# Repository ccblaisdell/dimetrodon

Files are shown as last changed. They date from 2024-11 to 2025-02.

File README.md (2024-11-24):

# Dimetrodon
A 36 key split keyboard with stagger and splay, built with Ergogen.

## Images
| Top | Bottom |
| --- | --- |
| top | bottom |

## Development

- Clone the git repository.
- Install NodeJS.
- Run `npm install`.
- Run `make build`.

## Case

### Development

When exporting the PCB STEP file from Kicad, be sure to choose the "Board center origin"
choice for the Coordinates option. This will undo the [100, -100] movement we define
in ergogen to make the file easier to work with in Kicad and center the model in 3d space.

## Acknowledgements

- Ergogen
- Rae-dux
- Totem
- FlatFootFox
- linalinn/kicad-render
- Scottokeebs

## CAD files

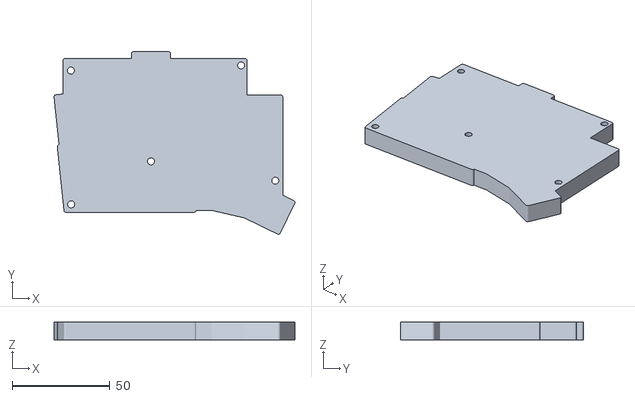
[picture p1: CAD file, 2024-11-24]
cases/case.stl
123.1 x 93.2 x 9.10

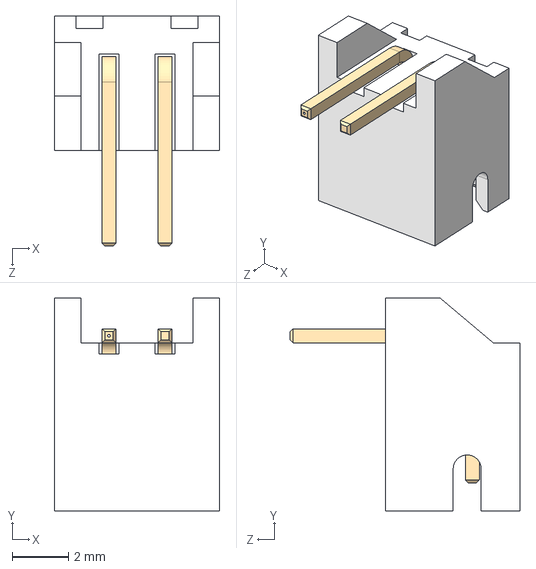
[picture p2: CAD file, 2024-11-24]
ergogen/3dmodels/JST-S2B-PH-K-S.STEP
5.90 x 7.60 x 8.20 mm

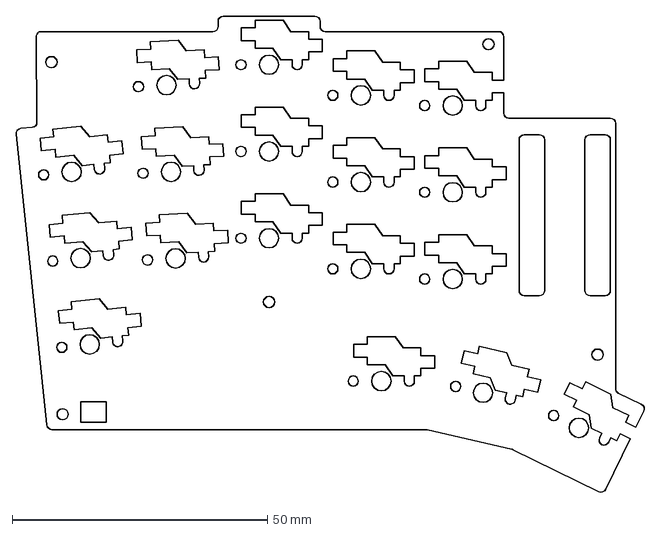
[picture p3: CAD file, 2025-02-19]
outlines/case_base_right.dxf
123.3 x 93.4 mm

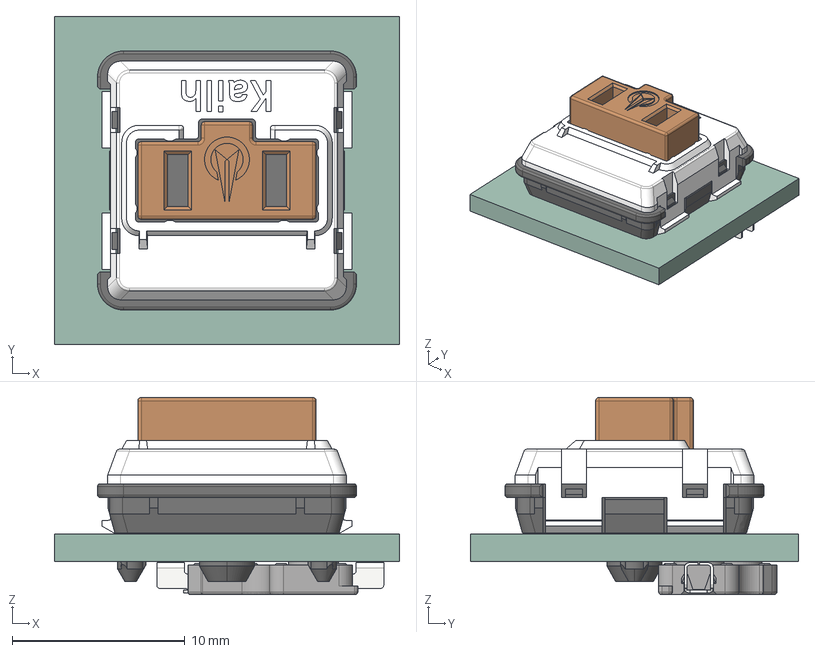
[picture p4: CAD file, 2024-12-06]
pcbs/single-choc-v1-hotswap.step
20.0 x 19.0 x 11.4 mm
SW_Hotswap_Kailh_Choc_v1
SW_Kailh_Choc_V1_cp
main (2)_PCB

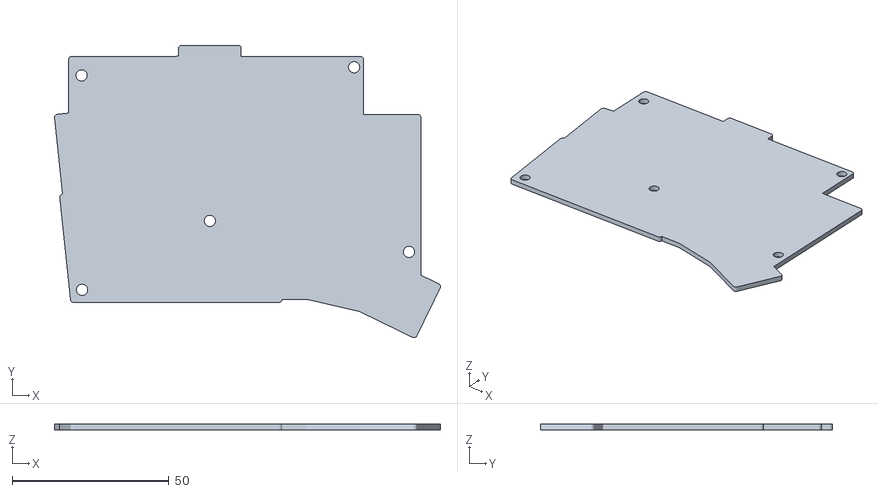
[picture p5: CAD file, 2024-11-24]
cases/cork_base.stl
123.1 x 93.2 x 1.80

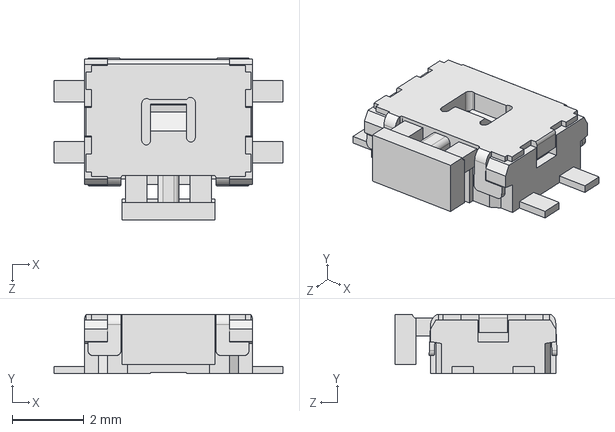
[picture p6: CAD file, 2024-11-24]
ergogen/3dmodels/EVQPU-JA-02K.STEP
6.40 x 1.65 x 4.54 mm

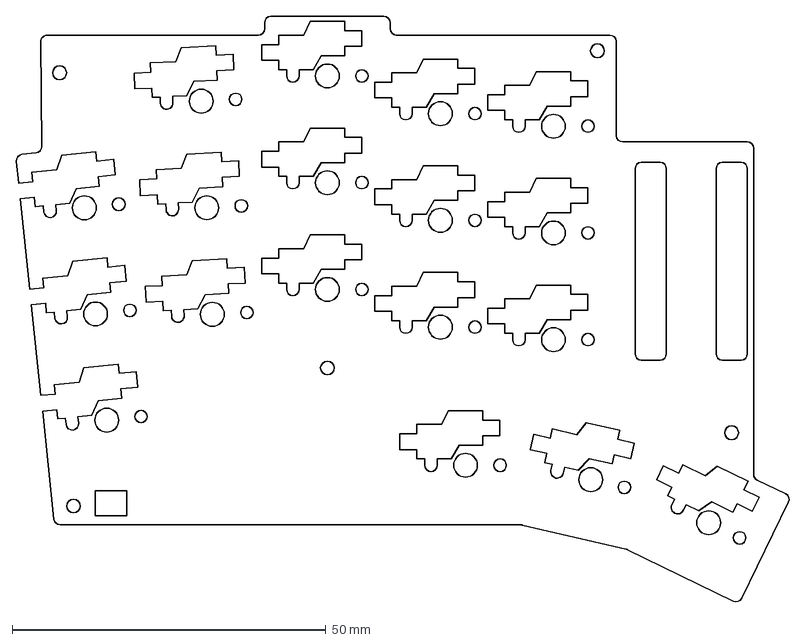
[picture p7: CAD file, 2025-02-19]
outlines/case_base_left.dxf
123.3 x 93.4 mm

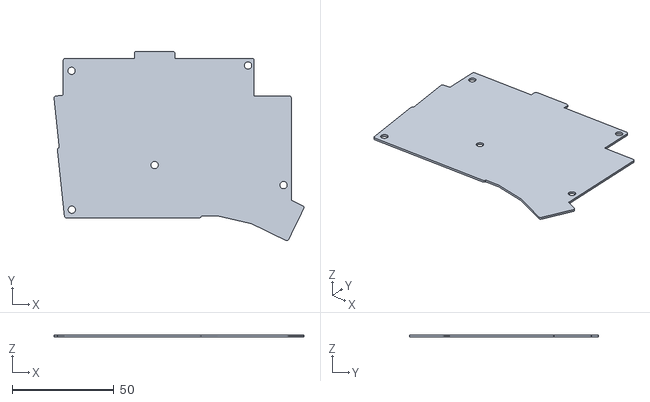
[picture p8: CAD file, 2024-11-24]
cases/silicone_base.stl
123.1 x 93.2 x 1.00

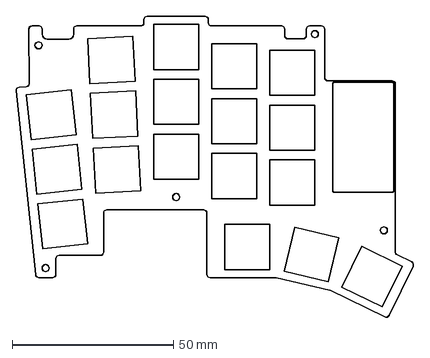
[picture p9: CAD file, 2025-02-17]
outlines/switch_plate.dxf
123.3 x 93.4 mm

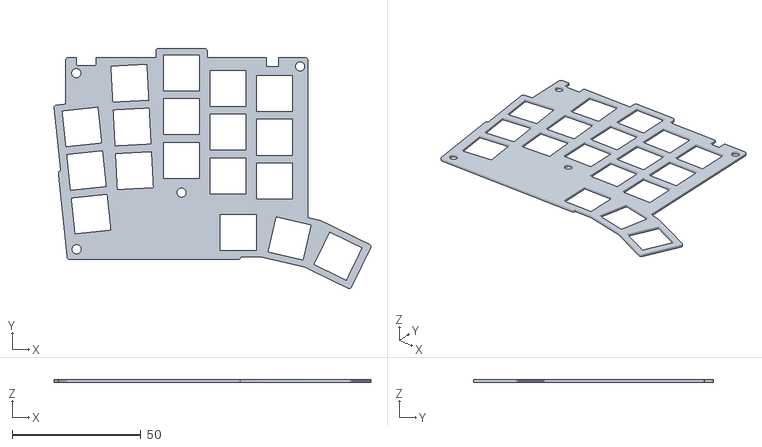
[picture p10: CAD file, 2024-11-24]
cases/gasket.stl
123.1 x 93.2 x 1.00

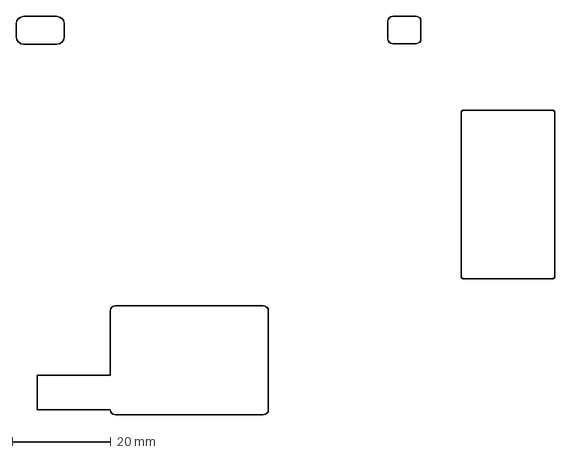
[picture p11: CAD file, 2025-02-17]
outlines/cavities.dxf
108.9 x 80.5 mm

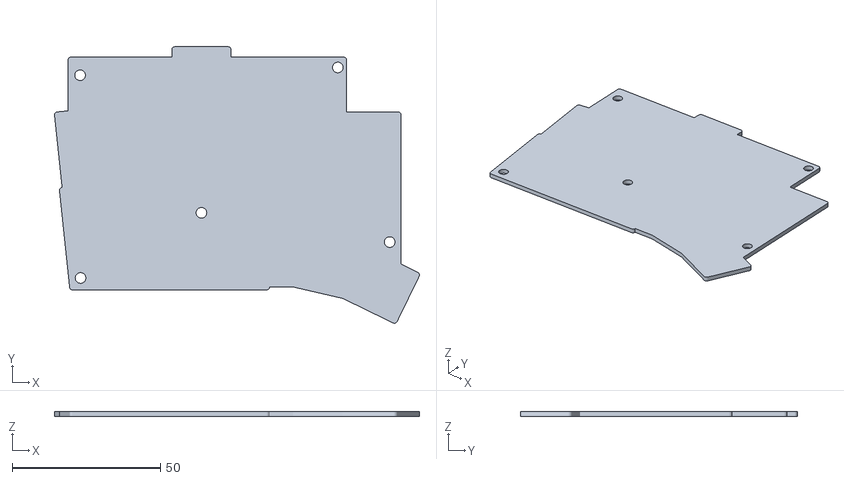
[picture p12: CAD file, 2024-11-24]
cases/pcb.stl
123.1 x 93.2 x 1.60

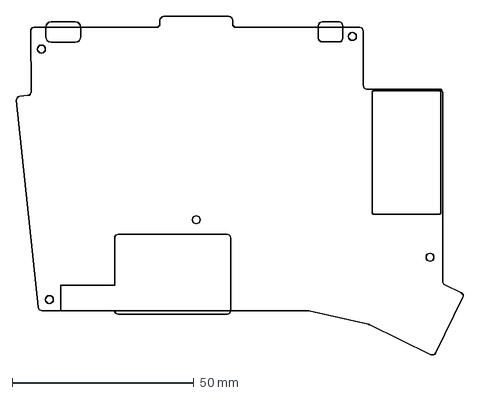
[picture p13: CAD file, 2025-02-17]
outlines/debug.dxf
123.3 x 93.4 mm

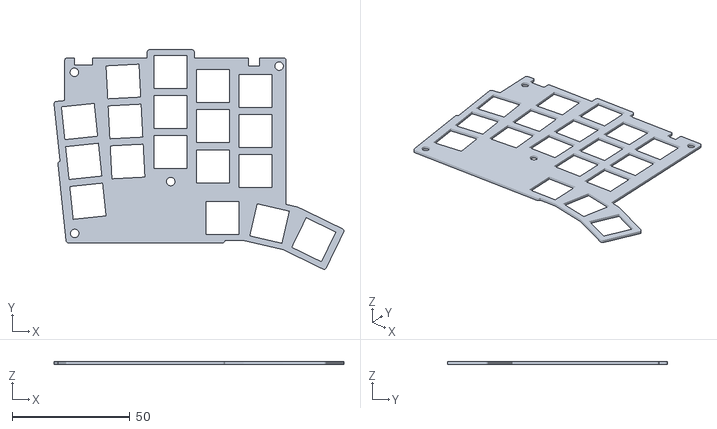
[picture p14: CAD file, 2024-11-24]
cases/switch_plate.stl
123.1 x 93.2 x 1.20

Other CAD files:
outlines/preview.dxf
outlines/left_board.dxf
outlines/base.dxf
outlines/keywell.dxf

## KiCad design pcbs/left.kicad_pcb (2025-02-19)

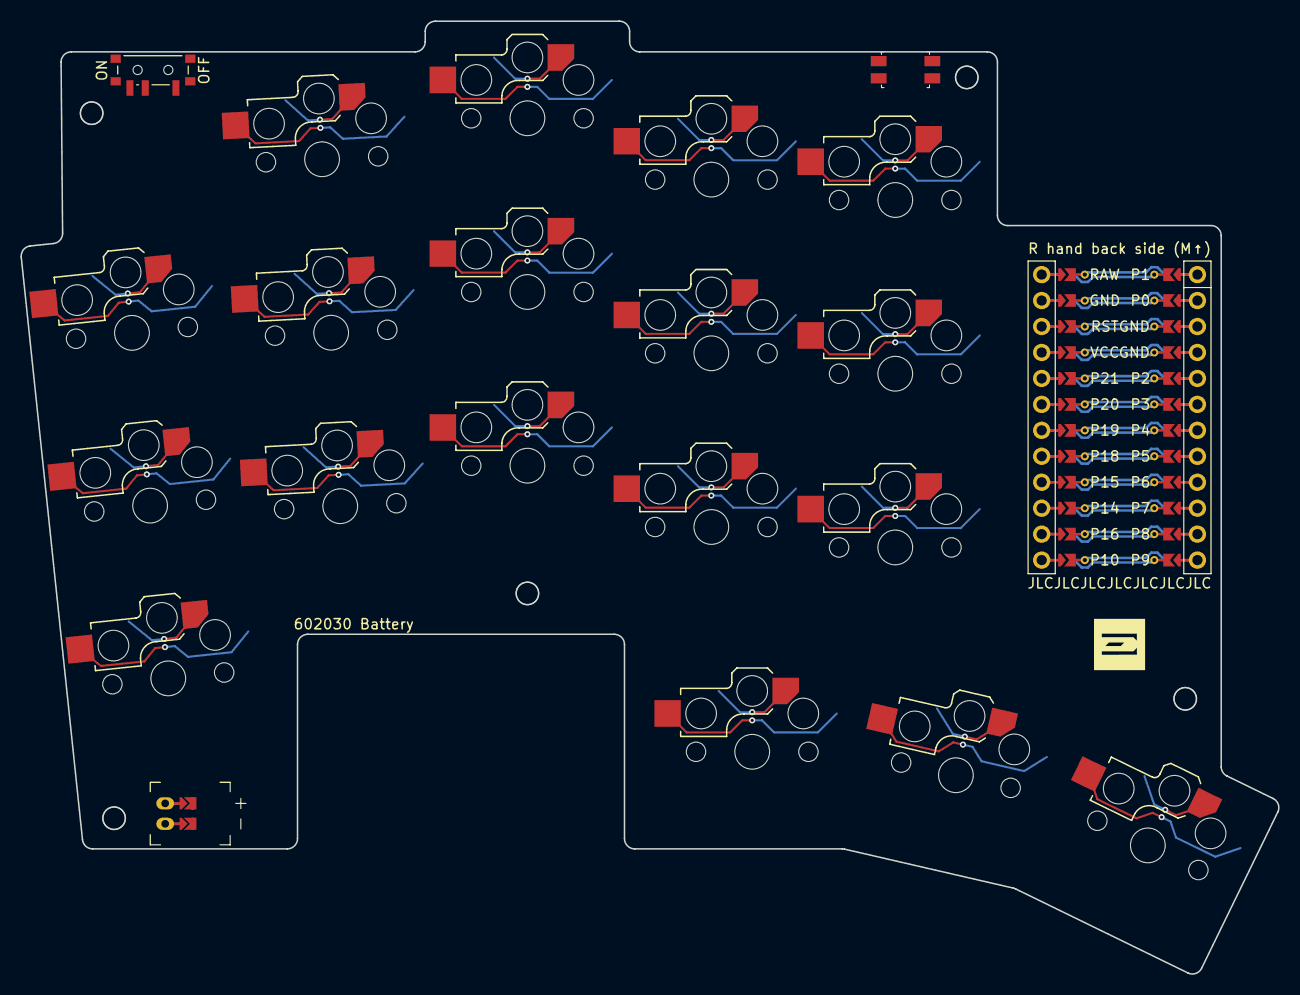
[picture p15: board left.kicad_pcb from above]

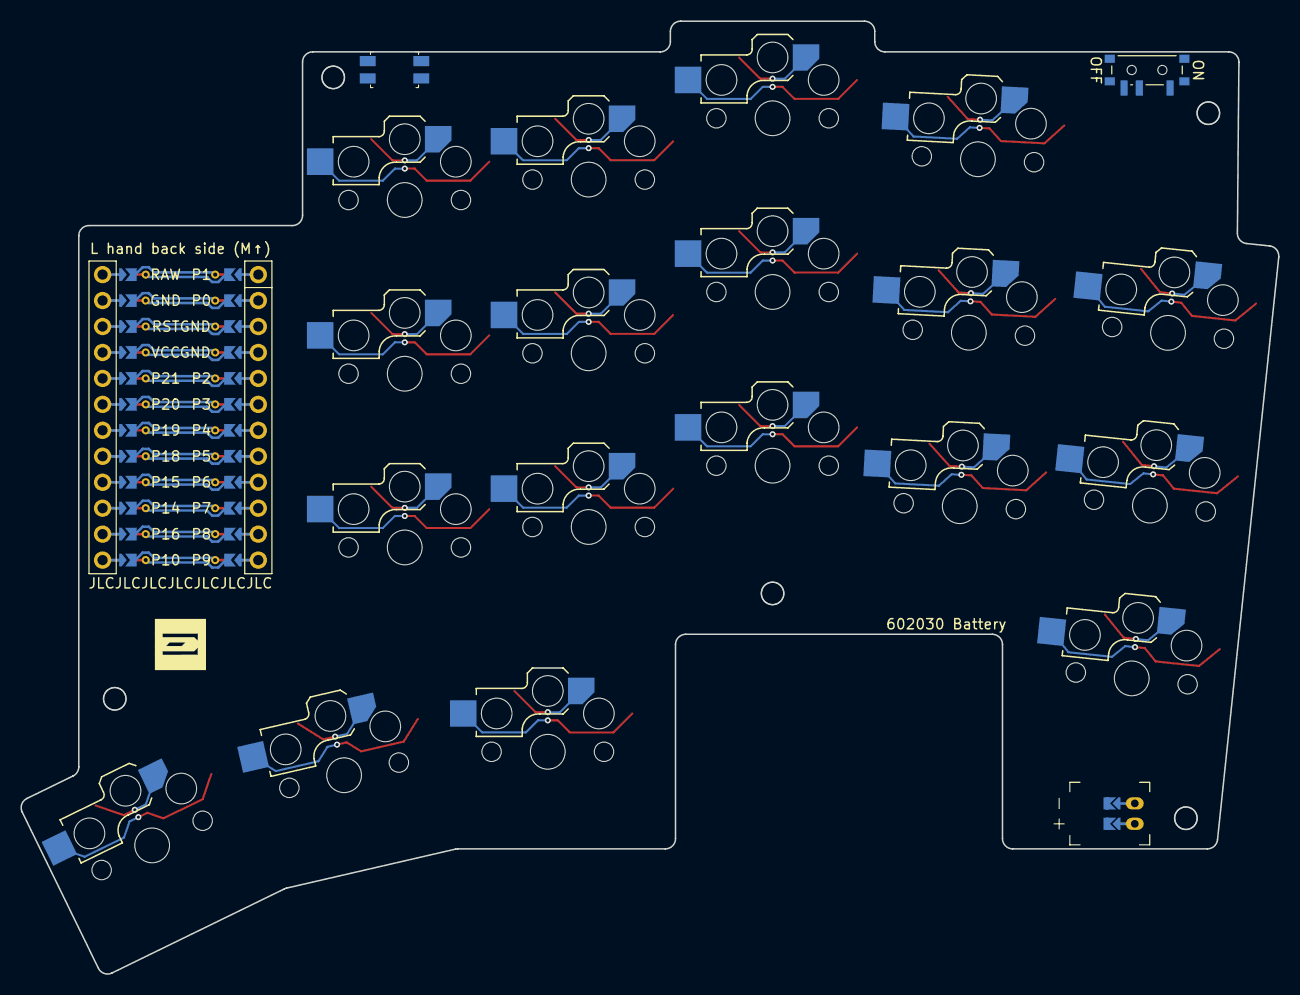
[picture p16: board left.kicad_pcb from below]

Board: 2 copper layers, 123.1 x 93.2 mm, 28 parts (18 on the bottom side), 24 nets.

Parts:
JST1: battery_connector_jst_ph_2
LOGO1: utility_ergogen_logo
MCU1: mcu_nice_nano
MH1, MH2, MH3, MH4, MH5: mounting_hole_npth
PWR1: power_switch_smd_side
RST1: reset_switch_smd_side
S1, S2, S3, S4, S5, S6, S7, S8, S9, S10, S11, S12, S13, S14, S15, S16, S17, S18: switch_choc_v1_v2

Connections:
Braw: JST1.1, PWR1.1, PWR1.3
GND: JST1.2, MCU1.103, MCU1.104, MCU1.123, RST1.1, RST1.3, S1.2, S2.2, S3.2, S4.2, S5.2, S6.2, S7.2, S8.2, S9.2, S10.2, S11.2, S12.2, S13.2, S14.2, S15.2, S16.2, S17.2, S18.2
JST1_1: JST1.11, JST1.21, JST1.31
JST1_2: JST1.12, JST1.22, JST1.32
P0: MCU1.102, S14.1
P1: MCU1.101, S15.1
P2: MCU1.105, S13.1
P3: MCU1.106, S12.1
P4: MCU1.107, S11.1
P5: MCU1.108, S10.1
P6: MCU1.109, S9.1
P7: MCU1.110, S8.1
P8: MCU1.111, S7.1
P9: MCU1.112, S6.1
P10: MCU1.113, S5.1
P14: MCU1.115, S3.1
P15: MCU1.116, S2.1
P16: MCU1.114, S4.1
P18: MCU1.117, S1.1
P19: MCU1.118, S16.1
P20: MCU1.119, S17.1
P21: MCU1.120, S18.1
RAW: MCU1.124, PWR1.2
RST: MCU1.122, RST1.2, RST1.4

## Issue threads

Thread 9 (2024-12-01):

Switch and pin cutouts for the base

ccblaisdell, 2024-12-01:
e.g. https://github.com/ImStuBTW/typeboy_and_typepak/blob/main/typeboy/footprints/chocbackplate.js

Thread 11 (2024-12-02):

Try to switch back off of custom footprints

ccblaisdell, 2024-12-02:
I switched to these so I could add 3d models for parts like the JST connector and reset/power switches.

Switch back to the ceoloide variety and make PRs if 3d models aren't provided. Use infused kim's models wherever possible.

- [x] Move back to ceoloide's `reset_switch` footprint
- [x] PR 3d model support for reset switch
- [x] Use infused kim's reset switch model
- [x] Move back to celoide's `jst_connector` footprint
- [x] PR 3d model support for jst connector
- [x] Use infused kim's choc hotswap model
- [x] Use infused kim's choc keycap model
- [x] Use infused kim's choc switch model
- [x] Use infused kim's nice nano model
- [x] Use infused kim's power switch model

Closed 2024-12-10.

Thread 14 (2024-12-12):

Case: Holes in top of screws

ccblaisdell, 2024-12-12:
Still not exactly sure how the screws should work. Maybe nuts and bolts? Anyway, they top probably needs some kind of countersunk areas for the tops.

A popular option is to use heat set inserts in the upper case that we will screw into from above and below

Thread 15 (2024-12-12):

Use holes for soldered battery instead of giant JST connector

ccblaisdell, 2024-12-12:
The JST connector is taller than I want to deal with. There are other options:

molex pico ezmate is said to lose retention after a few unplugs. JST ACH might be good too, but I think I just don't wanna mess with it. It will be easier to desolder the battery later.

ccblaisdell, 2024-12-12:
Ergogen discord sez just solder to the holes in the JST footprint and we're fine https://discord.com/channels/714176584269168732/759825860617437204/1316884986384875632

Closed 2024-12-12.

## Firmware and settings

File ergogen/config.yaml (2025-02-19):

meta:
  # Min Ergogen version for KiCad 8 footprints
  engine: 4.1.0
units:
  # Proxy spacing variables, choc spacing
  kx: cx
  ky: cy

  # For the preview at https://ergogen.ceoloide.com/
  $default_width: cx
  $default_height: cy

  # Switch padding, i.e. distance from center of switch (Point) to 
  # the nearest edge of the PCB. Essentially a 1mm pad. Useful
  # for adjustment operations in relation to a Point.
  cpx: 1 + kx / 2
  cpy: 1 + ky / 2

  # Controller dimensions
  nice_nano_length: 33
  nice_nano_width: 17.9
  xiao_length: 21
  xiao_width: 17.5

  # XX2030 battery
  battery_sm_width: 30
  battery_sm_length: 20

  # joycon battery
  battery_lg_width: 51
  battery_lg_length: 24.1

  # includes full courtyard size
  jst_connector_width: 12.35
  jst_connector_length: 6.9

  # The footprint's "origin" is not right in the center,
  # it's just a little ways from the left edge
  jst_connector_offset: -jst_connector_width / 2 + 1.85

  power_switch_width: 6.7
  power_switch_length: 2.6

  reset_switch_width: 4.7
  reset_switch_length: 3.5

  # Distance between highest finger and top of board
  middle_finger_prominence: 3

  mounting_hole_radius: 1.1

  total_matrix_splay: 6

  inner_to_mcu_distance: 4

  fan_outer_radius: 5kx

  #########
  # Cutouts
  #########

  # Choc stabilizer pin cutouts
  choc_stabilizer_cutout_offset_x: 5.5
  choc_stabilizer_cutout_radius: 1 # 0.9 on the spec

  # hotswap socket placement
  hotswap_socket_left_offset_x: -5 / 2
  hotswap_socket_right_offset_x: 5 / 2
  hotswap_socket_offset_y: 3.8 + (5.9 - 3.8) / 2
  hotswap_socket_left_offset_y: hotswap_socket_offset_y
  hotswap_socket_right_offset_y: hotswap_socket_offset_y

  # hotswap socket measurements
  hotswap_socket_lobe_width: 5.5 # 4.75 is the measurement on the specs
  hotswap_socket_lobe_height: 5.5 # 4.65 is the measurement on the specs
  hotswap_socket_connector_width: 2.7 # 2.6 is the measurement on the spec
  hotswap_socket_connector_height: 2.5 # 2.6 is the measurement on the spec
  
  # hotswap socket sub-component placement
  hotswap_socket_lobe_distance_x: 5 # between lobe centerpoints
  hotswap_socket_lobe_distance_y: 2.2

  # upper lobe
  hotswap_socket_upper_lobe_offset_x: hotswap_socket_lobe_distance_x / -2
  hotswap_socket_upper_lobe_offset_y: hotswap_socket_lobe_distance_y / -2
  hotswap_socket_upper_connector_offset_x: hotswap_socket_upper_lobe_offset_x - hotswap_socket_lobe_width / 2 - hotswap_socket_connector_width / 2
  hotswap_socket_upper_connector_offset_y: hotswap_socket_upper_lobe_offset_y
  
  # lower lobe
  hotswap_socket_lower_lobe_offset_x: hotswap_socket_lobe_distance_x / 2
  hotswap_socket_lower_lobe_offset_y: hotswap_socket_lobe_distance_y / 2
  hotswap_socket_lower_connector_offset_x: hotswap_socket_lower_lobe_offset_x + hotswap_socket_lobe_width / 2 + hotswap_socket_connector_width / 2
  hotswap_socket_lower_connector_offset_y: hotswap_socket_lower_lobe_offset_y
points:
  zones:
    matrix:
      anchor:
        # Cancel out rotations from column splay
        rotate: total_matrix_splay
        # Adjust translation for KiCad
        shift: [100, -100]
      key:
        padding: ky
        spread: kx
        tags: [key]
      columns:
        pinky:
          rows:
            bottom:
                column_net: P18
            home:
                column_net: P15
            top:
                column_net: P14
        ring:
          key:
            splay: -total_matrix_splay / 2
            spread: kx + 0.5
            stagger: ky - 2
          rows:
            bottom:
                column_net: P16
            home:
                column_net: P10
            top:
                column_net: P9
        middle:
          key:
            splay: -total_matrix_splay / 2
            spread: kx + 0.5
            stagger: 3
          rows:
            bottom:
                column_net: P8
            home:
                column_net: P7
            top:
                column_net: P6
        pointer:
          key:
            stagger: -6
          rows:
            bottom:
                column_net: P5
            home:
                column_net: P4
            top:
                column_net: P3
        inner:
          key:
            stagger: -2
          rows:
            bottom:
                column_net: P2
            home:
                column_net: P0
            top:
                column_net: P1
      rows:
        bottom:
        home:
        top:
    thumbs:
      anchor:
        ref: matrix_pointer_bottom
        shift: [4, -22]
      key:
        padding: 1ky
        spread: 1kx
        tags: [key]
      columns:
        tucky:
          key:
            column_net: P19
        middle:
          key:
            shift: [2.4, -1.8]
            splay: -13
            column_net: P20
        reachy:
          key:
            shift: [5.1, -3.2]
            splay: -13
            column_net: P21
      rows:
        cluster:
    case_tl:
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

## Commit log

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2024-11-17 Try generating images on github
    add github action from https://github.com/linalinn/kicad-render
    check in output files
    still need to run the build in GHA
    [board.dxf, combo.dxf, keycaps.dxf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]
2024-11-17 Fix path to pcb
2024-11-17 Fix path to pcb 2
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2024-11-18 Fix model names and generate
    [board.dxf, combo.dxf, keycaps.dxf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]
2024-11-18 Try to move MCU into place
    [left.kicad_pcb]
2024-11-18 Reset MCU y placement just to see
    [left.kicad_pcb]
2024-11-18 Shift MCU down 30mm
    [left.kicad_pcb]
2024-11-18 Shift MCU around a little more
    -1 ky, and raise up the 3d model just for the preview
    [left.kicad_pcb]
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2024-11-18 Undo reversibleness and mirror the sides
    [combo.dxf, keycaps.dxf, keywells.dxf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]
2024-11-18 Spread the splayed cols
    [board.dxf, combo.dxf, keycaps.dxf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]
2024-11-18 Move the nice nano
    [left.kicad_pcb]
2024-11-18 Make a switch plate outline
    [board.dxf, left.kicad_pcb, switch_holes.dxf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]
2024-11-19 Working on a better PCB outline
    [board.dxf, board2.dxf, left.kicad_pcb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]
2024-11-19 Cut a shrink-wrapped cheapino-style pcb
    [board2.dxf, left.kicad_pcb, matrix_bandaid.dxf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]
2024-11-19 Scoot the controller up
    [left.kicad_pcb]
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2024-11-19 Add PCB back for MCU
    [board2.dxf, controller_area.dxf, left.kicad_pcb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]
2024-11-19 Add reset and power switches
    [board2.dxf, controller_area.dxf, left.kicad_pcb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]
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2024-11-19 Add preview outline with battery and JST connector
    [left.kicad_pcb, preview.dxf, switch_plate.dxf]
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2024-11-19 Extend board under palm to hold battery and connector
    [left.kicad_pcb, left_board.dxf, preview.dxf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]
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2024-11-19 Add debug rectangle to locate power, reset switches
    [left.kicad_pcb, left_board.dxf, preview.dxf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]
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2024-11-19 Remove debug rect, add outlines to position reset/power switches
    [left.kicad_pcb, left_board.dxf, preview.dxf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]
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2024-11-19 Try to line up power/reset switches with their outlines
    [left.kicad_pcb]
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2024-11-19 More detailed outlines of power, reset
    [left.kicad_pcb, left_board.dxf, preview.dxf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]
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2024-11-19 Adjust power/reset a little more
    [left.kicad_pcb]
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2024-11-20 Use rae-dux style routing config
    for the choc switch footprint and the nice nano
    footprint. I'm using footprints from ceocloide,
    but copying config from Andrew J Rae:
    https://github.com/andrewjrae/rae-dux-v2/blob/development/config.yaml
    [left.kicad_pcb]
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2024-11-20 Move battery text the correct direction
    [left.kicad_pcb]
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2024-11-20 Position JST more robustly
    also tuck thumbs up a little more
    [left.kicad_pcb, left_board.dxf, preview.dxf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]
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2024-11-20 Try to share placement of controller outline + component
    [left.kicad_pcb]
2024-11-20 Fix bad math on controller outline
    [left.kicad_pcb, left_board.dxf, preview.dxf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]
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2024-11-20 Fix controller length
    [left.kicad_pcb, left_board.dxf, preview.dxf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]
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2024-11-21 Fix column nets
    [left.kicad_pcb]
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2024-11-22 Only required jumpers for the nice nano
    Most of them can be reversed in firmware
    [left.kicad_pcb]
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2024-11-22 Upload images to pages and fix pcb file ref
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2024-11-22 Undo last change and add 1mm around controller
    [left.kicad_pcb, left_board.dxf, preview.dxf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]
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2024-11-23 Remove temporary expands and move power switch slightly away from the edge
    [left.kicad_pcb, left_board.dxf, preview.dxf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]
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2024-11-23 Actually cut the battery area out of the PCB
    [left.kicad_pcb, left_board.dxf, preview.dxf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]
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2024-11-24 Cut out jst, reset, power from switch plate
    [base.dxf, case.stl, cork_base.stl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]
2024-11-24 Fix little wrinkle on left edge
    [base.dxf, keywell.dxf, left.kicad_pcb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]
2024-11-24 Use 3d models in ergogen config, export STEP of pcb and components
    [Choc_V1_Keycap_MBK_Black_1u.step, Choc_V1_Keycap_MBK_Red_1u.step, Choc_V1_Keycap_MBK_White_1u.step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]
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2024-11-24 Add a little extra padding to the matrix
    [base.dxf, keywell.dxf, left.kicad_pcb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]
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2024-11-25 Expand controller cover by 0.5, still not sure where errors are coming from
    [base.dxf, left.kicad_pcb, left_board.dxf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]
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2024-11-25 Adjust how far middle finger sticks out from the top
    shooting in the dark to try and fix this edge issue
    [base.dxf, left.kicad_pcb, left_board.dxf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]
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2024-11-25 Restore 'controller_area' outline
    controller_cover now subtracts from this. the area outline will
    be used in pcb and other outlines that are actually functional,
    and cover will just be used for the case.
    [base.dxf, left.kicad_pcb, left_board.dxf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]
2024-11-25 Restore the top left mounting hole. Hope it works!
    [base.dxf, left.kicad_pcb, left_board.dxf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]
2024-11-25 Move top left hole down, trying to prevent it from overlapping any other pad
    [base.dxf, left.kicad_pcb, left_board.dxf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]
2024-11-25 Disable copper fill to see if it fixes the hole issues
    [left.kicad_pcb]
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2024-11-25 Try a better wiring setup, maybe its more solvable
    [case.stl, cork_base.stl, gasket.stl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]
2024-11-25 Swap around a few pin assignments
    [left.kicad_pcb]
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2024-11-26 Revert "Wire rows first instead of cols first"
    This reverts commit 3c4794044432473890ef1c2f8a1e804d3262da1d.
    [left.kicad_pcb]
2024-11-26 Revert "Swap around a few pin assignments"
    This reverts commit 49207986db77539a4d281e71b42a971c91786d55.
    [left.kicad_pcb]
2024-11-26 Revert "Try a better wiring setup, maybe its more solvable"
    This reverts commit 779ee643710634eb545d8b17a1ea1ffac16ddf0a.
    [case.stl, cork_base.stl, gasket.stl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]
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2024-11-27 Remove all filleting
    will need to add this back in for the PCB, but the filleting
    is weird on some of the outlines, so will need to add them
    back in piecemeal.
    Also added tags to the keys and notes for making a Point-
    centric config.
    [base.dxf, keywell.dxf, left.kicad_pcb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]
2024-11-27 Set up empty points, convert mcu to point
    [preview.dxf]
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2024-11-28 Convert top right corner to a point
    Also make both top left and top right points intersections
    with the top of the keyboard and the top corner key.
    [base.dxf, left.kicad_pcb, left_board.dxf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]
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2024-11-28 Redefine several areas in relation to new points
    [base.dxf, left.kicad_pcb, left_board.dxf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]
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2024-11-28 Make mcu connection to thumb fan a little more robust
    [base.dxf, left.kicad_pcb, left_board.dxf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]
2024-11-29 Fix optical alignment between jst outline and footprint
    [left.kicad_pcb, preview.dxf, switch_plate.dxf]
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2024-11-29 Fix rotation of switch and hotswap models for left hand
    [left.kicad_pcb]
2024-12-02 Move back to ceoloide footprints
    for JST and reset switch
    [left.kicad_pcb]
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2024-12-02 #7 Add left edge to thumb fan case
    [preview.dxf]
2024-12-04 Convert left edge of thumb fan case to points
    [base.dxf, left.kicad_pcb, left_board.dxf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]
2024-12-06 Add model for single hotswap, for use in creating a cutout footprint
    [left.kicad_pcb, single-choc-v1-hotswap.kicad_pcb, single-choc-v1-hotswap.step]
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2024-12-13 Add tenting puck, need to test in KiCad
    [left.kicad_pcb]
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2025-01-16 Add all 3d models back into PCB file
    re-added infused kim footprints, the source of some of
    the 3d models. Uncommented model config in ergogen yml.
    Regenerated PCB
    [left.kicad_pcb]
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2025-01-18 Make 3d model have a 1.2mm thick PCB
    [left.kicad_pcb]
2025-02-17 Add DXF npm package for converting DXF to svg
    [case_base_left.dxf, case_base_right.dxf, cavities.dxf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]
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2025-02-19 Added dxf-to-svg npm script to be used later
    [left.kicad_pcb]
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
